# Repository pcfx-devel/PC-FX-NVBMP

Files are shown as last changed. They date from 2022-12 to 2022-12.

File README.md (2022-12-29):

# PC-FX-NVBMP

This is a design of a non-volatile backup memory board for the PC-FX. It's based on the
FX-BMP, but doesn't need batteries, and allows for several different sizes.

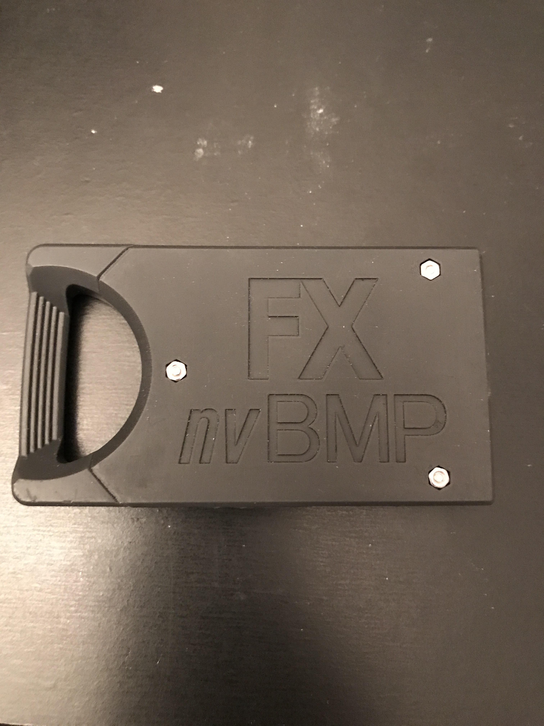
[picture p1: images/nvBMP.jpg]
FX-nvBMP cartridge


## Design

I designed the board using the free version of EAGLE, which is limited to 2 layers and
100mm x 100mm board size.  I have included the project files as well as the gerber outputs.

The board design is "Rev_B", as there was a minor fault in the REV_A design.

## Assembly

I have included gerber files, as well as BOM.csv and assembly.csv files, for use with
JLCPCB's SMD assembly service, if you are interested in taking advantage of that.

The second time I tried to order, the MRAM chip was no longer available, and I have noticed
in the past that the empty area would be filled with solder paste and would not be smooth
upon delivery, making it more difficult to solder my own parts on... so I made a special
"empty_MRAM_variant" set of gerbers/BOM.csv/assembly.csv files. The way I used these was to
order boards for assembly (including the level shift, OR gates, voltage regulator, and all the
passive components except the capactiors next to the MRAM chip; I sheared the stencil slightly
above the MRAM chip, and used the stencil to apply solder paste for just the MRAM chip and
2 capacitors, using a hotplate to heat the boards after mounting the missing parts.

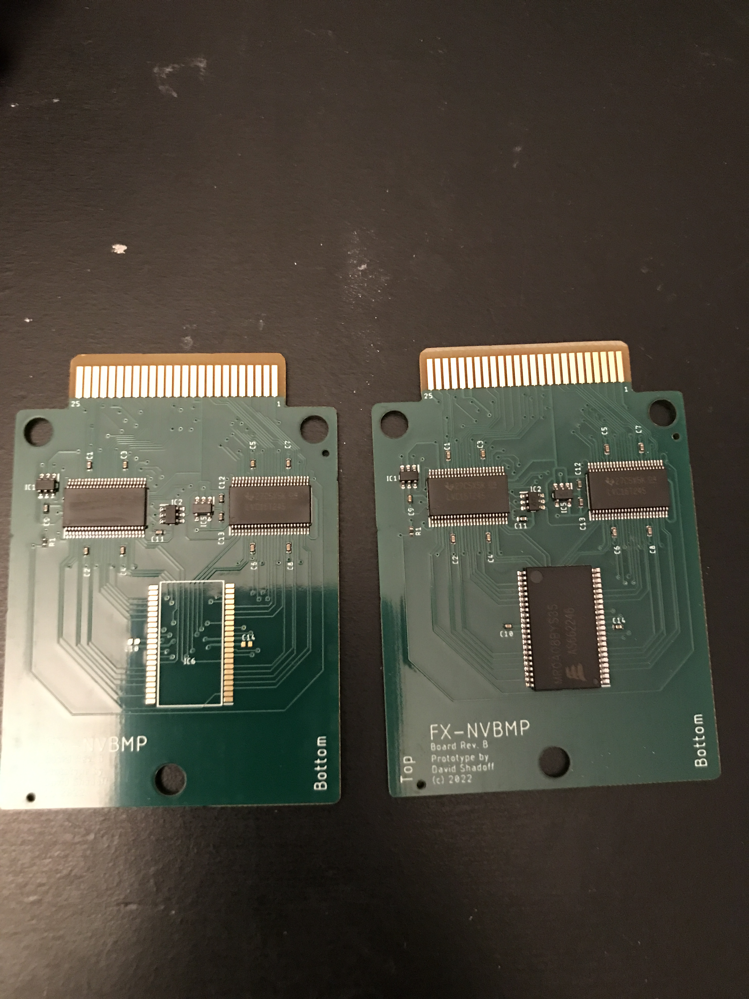
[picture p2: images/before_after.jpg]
empty_MRAM_variant


The MRAM part in use is MR0A08BCYS35 (TSOP2-44 package), but you could substitute any
other MR0A08... chip which uses the TSOP2-44 package (the 'Y' indicates this).
Additionally, MR2A08... (512KB) or MR4A08... (2MB) chips in the same line will also be
compatible as long as they also use the TSOP2-44 package.

## Case

You can also find the design for a case/enclosure, courtesy of Jeff Chen (Twitter: @jeffqchen).
This is suitable for any 3D printer; I particularly liked the resin prints I ordered online.
The case is designed to accept M2-12 socket-head screws and nuts.

## Circuit Design Concepts

I had originally considered using FRAM (Ferroelectric RAM) as the non-volatile memory type,
but when I went to search for parts, the 28V100 part was out of stock and had increased in
price significantly.  The next choice was MRAM (magnetoresistive RAM), which was available
(in very small quantities), slightly cheaper, and also had larger chips in the line which
shared the same footprint and pinout, so the board could be designed to accommodate the larger
chips without any changes (up to 2MB).

Also important, the pinout of the MRAM chip was very similar to the pinout of the FX-BMP
port, so a 2-layer board coul be made to accommodate it easier than FRAM.

As the PC-FX uses a 5V bus and these chips are based on 3V logic, level-shifters were required.

In order to drive the chip-select (low), a 3-input OR gate is used, requiring the following
lines to ALL be low in order to trigger the chip select:
 1. Cartridge select (keys in on range 0xE8000000 - 0xEFFFFFFF)
 2. A25 (narrows the range to 0xE8000000 - 0xEBFFFFFF)
 3. A24 (narrows the range to 0xE8000000 - 0xE9FFFFFF)

**NOTE:**\
The address lines are numbered according to the chip's address lines, which are not
necessarily the same as the CPU's address lines. The second byte on the memory chip is
actually memory address 0xE8000002, so the memory chip's A0 is effectively the CPU's A1).

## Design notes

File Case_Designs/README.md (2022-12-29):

# Case_Designs

These case deisgns were made Jeff Chen (Twitter: @jeffqchen), who has
graciously granted me permission to put them into the repository together
with the PC Board designs.

### Version 1:

This was a left/right half-case with similar dimensions to the original
PC-FX FX-BMP case.

It is designed to be held together by M2-12 screws (qty 3).

### Version 2:

This version made the sides slightly more asymmetric, with a carve-out on the
handle where the recess is on the PC-FX (to make it easier to remove).
Diagonals on the left side help guide the right side into place (although
there is a small amount of "rotation" possible).

There are also two different right-halves, one for the nvBMP, and one for the
Flash cartridge.

### Version 3:

This version has two principal changes from Version 2:

 1. There are "wells" on the left half to allow for the throuhg-hole pins of
the DIP version of the Flash board to be seated properly.
 2. In order to prevent the "rotation" when aligning the opposite sides, there
are interlocking notches on the diagonals. These can be a bit tight, but definitely
make a good mechinical alignment between sides for faster assembly with the screws.

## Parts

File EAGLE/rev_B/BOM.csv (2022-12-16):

Qty | Designator | Footprint | Comment | LCSC Part # (optional) | Description (optional)
12 | C1, C2, C3, C4, C5, C6, C7, C8, C9, C10, C11, C14 | C0402 | 100nF 16V | C1525 | Samsung CL05B104KO5NNNC 100nF 16V 0402
2 | C12, C13 | C0402 | 1uF 25V | C52923 | Samsung CL05A105KA5NQNC 1uF 25V 0402
1 | R1 | R0402 | 47K | C25741 | 62.5mW Thick Film Resistors 50V ±100ppm/_ ±1% -55_~+155_ 100k½ 0402 Chip Resistor - Surface Mount ROHS
2 | IC3, IC4 | TSSOP-48 | 74LVC16T245DGGR | C148170 | Texas Instruments 74LVC16T245DGGR, Dual, Bus Transceiver, 16-Bit Non-Inverting LVTTL, 1.65 5.5 V, 48-Pin TSSOP
2 | IC1, IC2 | SOT-23-6 | 74LVC1G332DBVR | C43368 | Texas Instruments 74LVC1G332DBVR, 3-Input OR Logic Gate, 1.65 5.5 V, 6-Pin SOT-23
1 | U$2 | Do Not Populate | Do Not Populate | Do Not Populate | Do Not Populate
1 | IC5 | SOT-23-5 | MIC5504-3.3YM5-TR | C88419 | 300mA 60dB@(1kHz) 380mV@(300mA) Fixed 3.3V~3.3V Positive 1 5.5V SOT-23-5 Linear Voltage Regulators (LDO) ROHS
1 | IC6 | TSOP2-44 | MR0A08BCYS35 | C246239 | Everspin MRAM 1Mb 3.3V 128Kx8 35ns Parallel MRAM

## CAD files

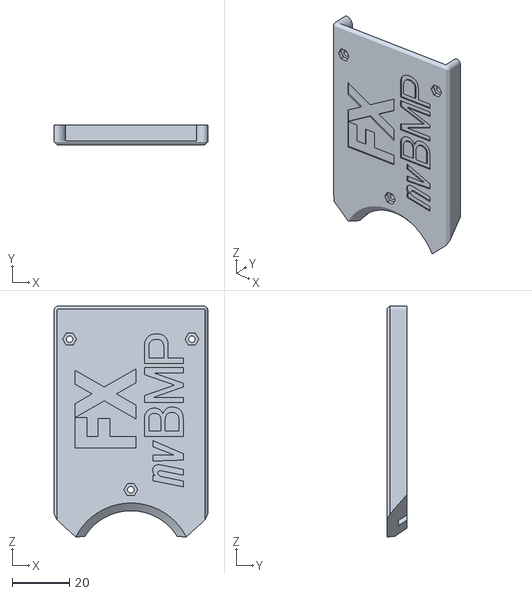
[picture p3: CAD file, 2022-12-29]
Case_Designs/Ver_3/Shell Right_mk3 - nvBMP.stl
53.8 x 7.03 x 80.8

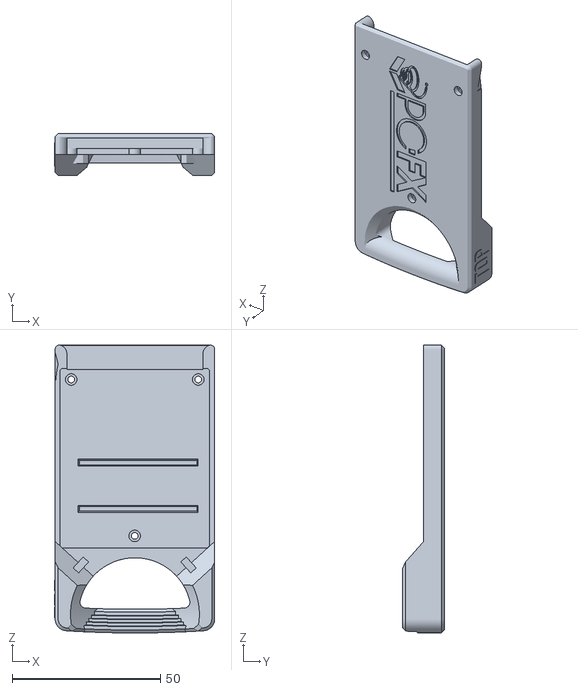
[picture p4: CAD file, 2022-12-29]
Case_Designs/Ver_3/Shell Left_mk3.stl
54.1 x 14.0 x 97.0

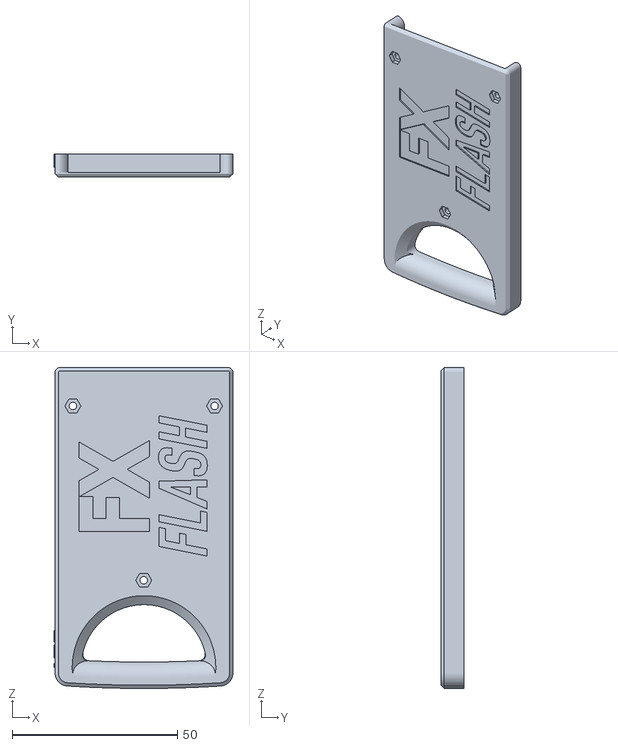
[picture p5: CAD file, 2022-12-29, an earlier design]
Case_Designs/Ver_1/Shell Right_orig.stl
54.1 x 7.03 x 97.0

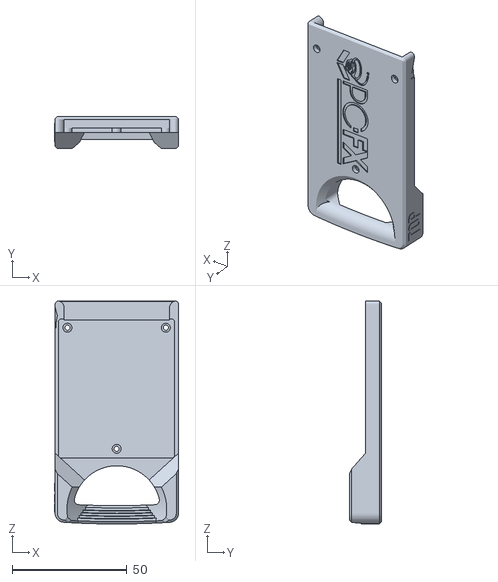
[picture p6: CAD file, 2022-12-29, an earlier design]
Case_Designs/Ver_2/Shell Left_mk2.stl
54.1 x 14.0 x 97.0

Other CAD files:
Case_Designs/Ver_3/Shell Right_mk3 - Flash.stl
Case_Designs/Ver_2/Shell Right_mk2 - nvBMP.stl
Case_Designs/Ver_1/Shell Left_orig.stl
Case_Designs/Ver_2/Shell Right_mk2 - Flash.stl

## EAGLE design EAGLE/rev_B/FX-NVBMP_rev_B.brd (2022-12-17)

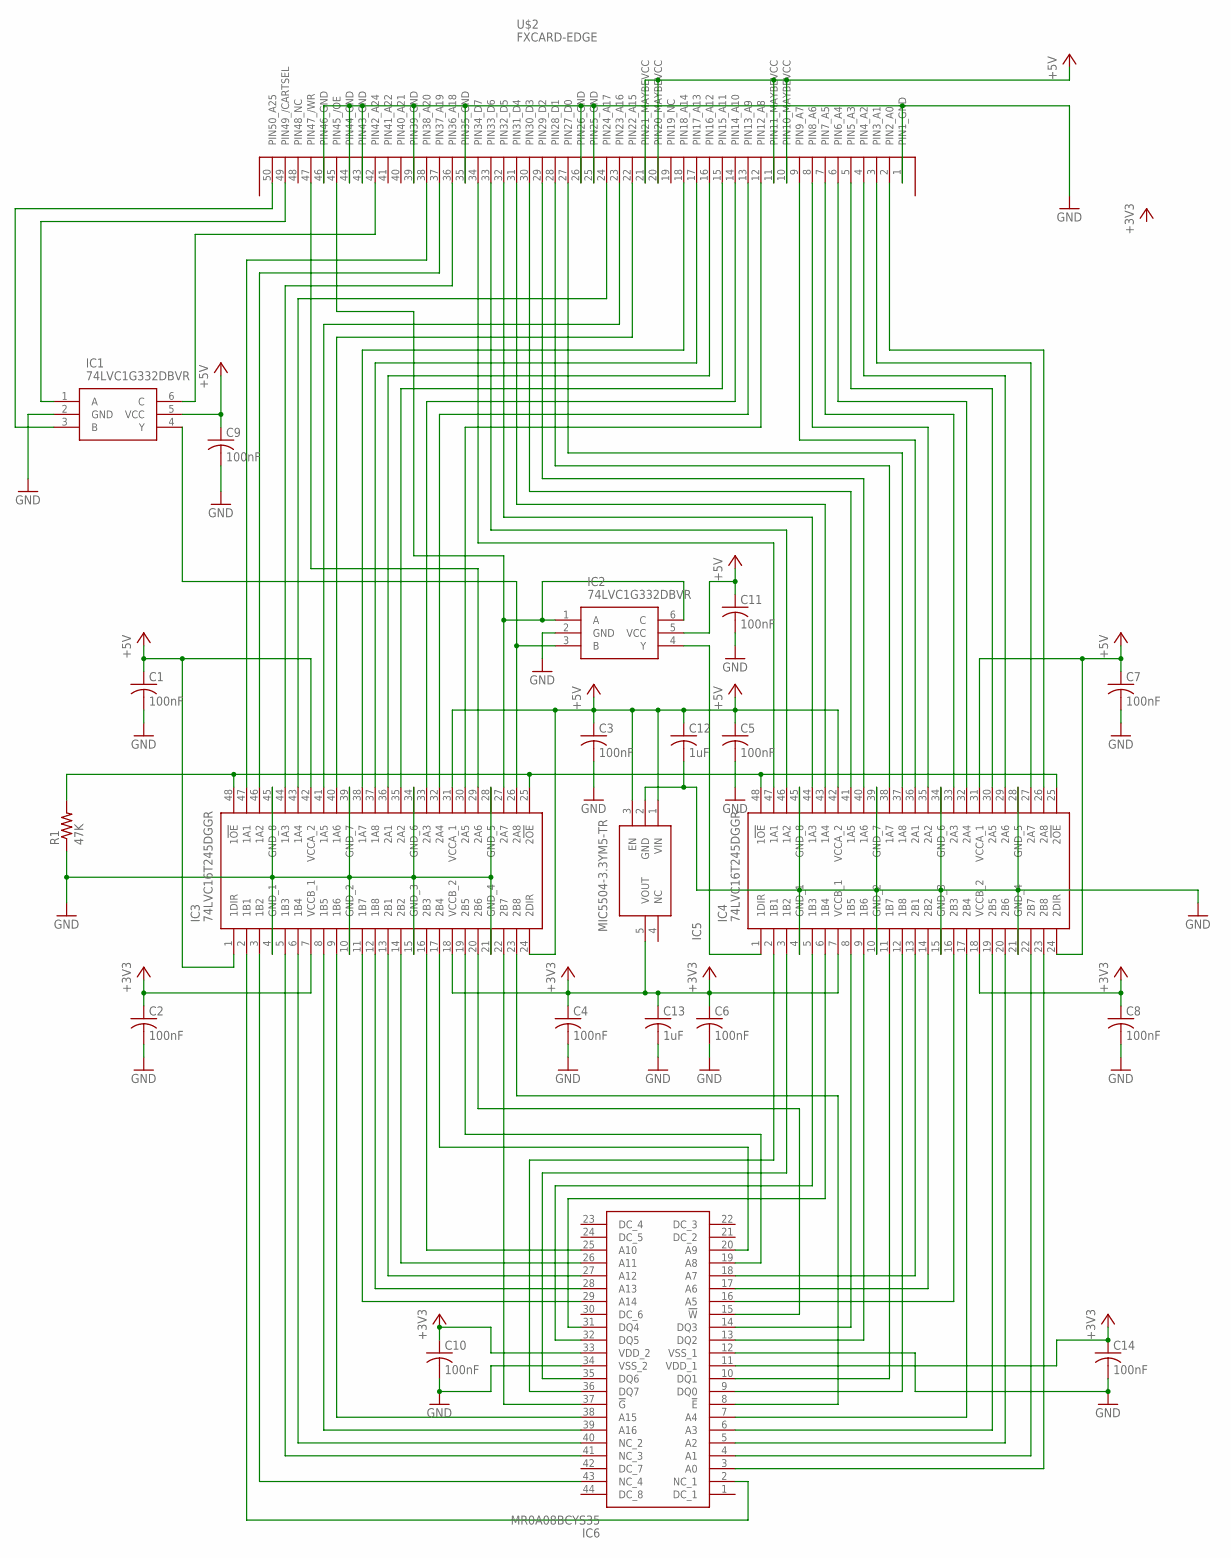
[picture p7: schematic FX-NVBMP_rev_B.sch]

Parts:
C1, C2, C3, C4, C5, C6, C7, C8, C9, C10, C11, C14: 100nF; C0402
C12, C13: 1uF; C0402
IC1, IC2: 74LVC1G332DBVR; SOT95P280X145-6N
IC3, IC4: 74LVC16T245DGGR; SOP50P810X120-48N
IC5: MIC5504-3.3YM5-TR; SOT95P280X145-5N
IC6: MR0A08BCYS35; SOP80P1176X120-44N
R1: 47K; R0402
U$2: FXCARD-EDGE

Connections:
+3V3: C2.1, C4.1, C6.1, C8.1, C10.1, C13.1, C14.1, IC3.7 (VCCB_1), IC3.18 (VCCB_2), IC4.7 (VCCB_1), IC4.18 (VCCB_2), IC5.5 (VOUT), IC6.11 (VDD_1), IC6.33 (VDD_2)
+5V: C1.1, C3.1, C5.1, C7.1, C9.1, C11.1, C12.1, IC1.5 (VCC), IC2.5 (VCC), IC3.1 (1DIR), IC3.24 (2DIR), IC3.31 (VCCA_1), IC3.42 (VCCA_2), IC4.24 (2DIR), IC4.31 (VCCA_1), IC4.42 (VCCA_2), IC5.1 (VIN), IC5.3 (EN), U$2.10 (PIN10_MAYBEVCC), U$2.11 (PIN11_MAYBEVCC), U$2.20 (PIN20_MAYBEVCC), U$2.21 (PIN21_MAYBEVCC)
GND: C1.2, C2.2, C3.2, C4.2, C5.2, C6.2, C7.2, C8.2, C9.2, C10.2, C11.2, C12.2, C13.2, C14.2, IC1.2 (GND), IC2.2 (GND), IC3.4 (GND_1), IC3.10 (GND_2), IC3.15 (GND_3), IC3.21 (GND_4), IC3.28 (GND_5), IC3.34 (GND_6), IC3.39 (GND_7), IC3.45 (GND_8), IC4.4 (GND_1), IC4.10 (GND_2), IC4.15 (GND_3), IC4.21 (GND_4), IC4.28 (GND_5), IC4.34 (GND_6), IC4.39 (GND_7), IC4.45 (GND_8), IC5.2 (GND), IC6.12 (VSS_1), IC6.34 (VSS_2), R1.1, U$2.1 (PIN1_GND), U$2.25 (PIN25_GND), U$2.26 (PIN26_GND), U$2.35 (PIN35_GND), U$2.39 (PIN39_GND), U$2.43 (PIN43_GND), U$2.44 (PIN44_GND), U$2.46 (PIN46_GND)
unnamed: IC4.37 (1A8), U$2.27 (PIN27_D0)
unnamed: IC4.38 (1A7), U$2.28 (PIN28_D1)
unnamed: IC4.40 (1A6), U$2.29 (PIN29_D2)
unnamed: IC4.41 (1A5), U$2.30 (PIN30_D3)
unnamed: IC4.43 (1A4), U$2.31 (PIN31_D4)
unnamed: IC4.44 (1A3), U$2.32 (PIN32_D5)
unnamed: IC4.46 (1A2), U$2.33 (PIN33_D6)
unnamed: IC4.47 (1A1), U$2.34 (PIN34_D7)
unnamed: IC4.26 (2A8), U$2.2 (PIN2_A0)
unnamed: IC4.27 (2A7), U$2.3 (PIN3_A1)
unnamed: IC4.29 (2A6), U$2.4 (PIN4_A2)
unnamed: IC4.30 (2A5), U$2.5 (PIN5_A3)
unnamed: IC4.33 (2A3), U$2.7 (PIN7_A5)
unnamed: IC3.43 (1A4), U$2.24 (PIN24_A17)
unnamed: IC4.35 (2A2), U$2.8 (PIN8_A6)
unnamed: IC4.36 (2A1), U$2.9 (PIN9_A7)
unnamed: IC4.32 (2A4), U$2.6 (PIN6_A4)
unnamed: IC3.44 (1A3), U$2.36 (PIN36_A18)
unnamed: IC3.46 (1A2), U$2.37 (PIN37_A19)
unnamed: IC3.47 (1A1), U$2.38 (PIN38_A20)
unnamed: IC1.4 (Y), IC2.3 (B), IC3.26 (2A8)
unnamed: IC3.25 (2!OE), IC3.48 (1!OE), IC4.25 (2!OE), IC4.48 (1!OE), R1.2
unnamed: IC4.23 (2B8), IC6.3 (A0)
unnamed: IC4.22 (2B7), IC6.4 (A1)
unnamed: IC4.20 (2B6), IC6.5 (A2)
unnamed: IC2.4 (Y), IC4.1 (1DIR)
unnamed: IC4.19 (2B5), IC6.6 (A3)
unnamed: IC4.17 (2B4), IC6.7 (A4)
unnamed: IC4.16 (2B3), IC6.16 (A5)
unnamed: IC4.14 (2B2), IC6.17 (A6)
unnamed: IC4.13 (2B1), IC6.18 (A7)
unnamed: IC4.12 (1B8), IC6.9 (DQ0)
unnamed: IC3.30 (2A5), U$2.12 (PIN12_A8)
unnamed: IC3.32 (2A4), U$2.13 (PIN13_A9)
unnamed: IC3.33 (2A3), U$2.14 (PIN14_A10)
unnamed: IC3.35 (2A2), U$2.15 (PIN15_A11)
unnamed: IC3.36 (2A1), U$2.16 (PIN16_A12)
unnamed: IC3.37 (1A8), U$2.17 (PIN17_A13)
unnamed: IC3.38 (1A7), U$2.18 (PIN18_A14)
unnamed: IC3.40 (1A6), U$2.22 (PIN22_A15)
unnamed: IC3.41 (1A5), U$2.23 (PIN23_A16)
unnamed: IC3.29 (2A6), U$2.47 (PIN47_/WR)
unnamed: IC2.1 (A), IC2.6 (C), IC3.27 (2A7), U$2.45 (PIN45_/OE)
unnamed: IC1.3 (B), U$2.50 (PIN50_A25)
unnamed: IC1.1 (A), U$2.49 (PIN49_/CARTSEL)
unnamed: IC1.6 (C), U$2.42 (PIN42_A24)
unnamed: IC4.11 (1B7), IC6.10 (DQ1)
unnamed: IC4.9 (1B6), IC6.13 (DQ2)
unnamed: IC4.8 (1B5), IC6.14 (DQ3)
unnamed: IC4.6 (1B4), IC6.31 (DQ4)
unnamed: IC4.5 (1B3), IC6.32 (DQ5)
unnamed: IC4.3 (1B2), IC6.35 (DQ6)
unnamed: IC4.2 (1B1), IC6.36 (DQ7)
unnamed: IC3.19 (2B5), IC6.19 (A8)
unnamed: IC3.17 (2B4), IC6.20 (A9)
unnamed: IC3.16 (2B3), IC6.25 (A10)
unnamed: IC3.14 (2B2), IC6.26 (A11)
unnamed: IC3.13 (2B1), IC6.27 (A12)
unnamed: IC3.12 (1B8), IC6.28 (A13)
unnamed: IC3.11 (1B7), IC6.29 (A14)
unnamed: IC3.9 (1B6), IC6.38 (A15)
unnamed: IC3.8 (1B5), IC6.39 (A16)
unnamed: IC3.6 (1B4), IC6.40 (NC_2)
unnamed: IC3.5 (1B3), IC6.41 (NC_3)
unnamed: IC3.3 (1B2), IC6.43 (NC_4)
unnamed: IC3.2 (1B1), IC6.2 (NC_1)
unnamed: IC3.20 (2B6), IC6.15 (!W)
unnamed: IC3.23 (2B8), IC6.8 (!E)
unnamed: IC3.22 (2B7), IC6.37 (!G)

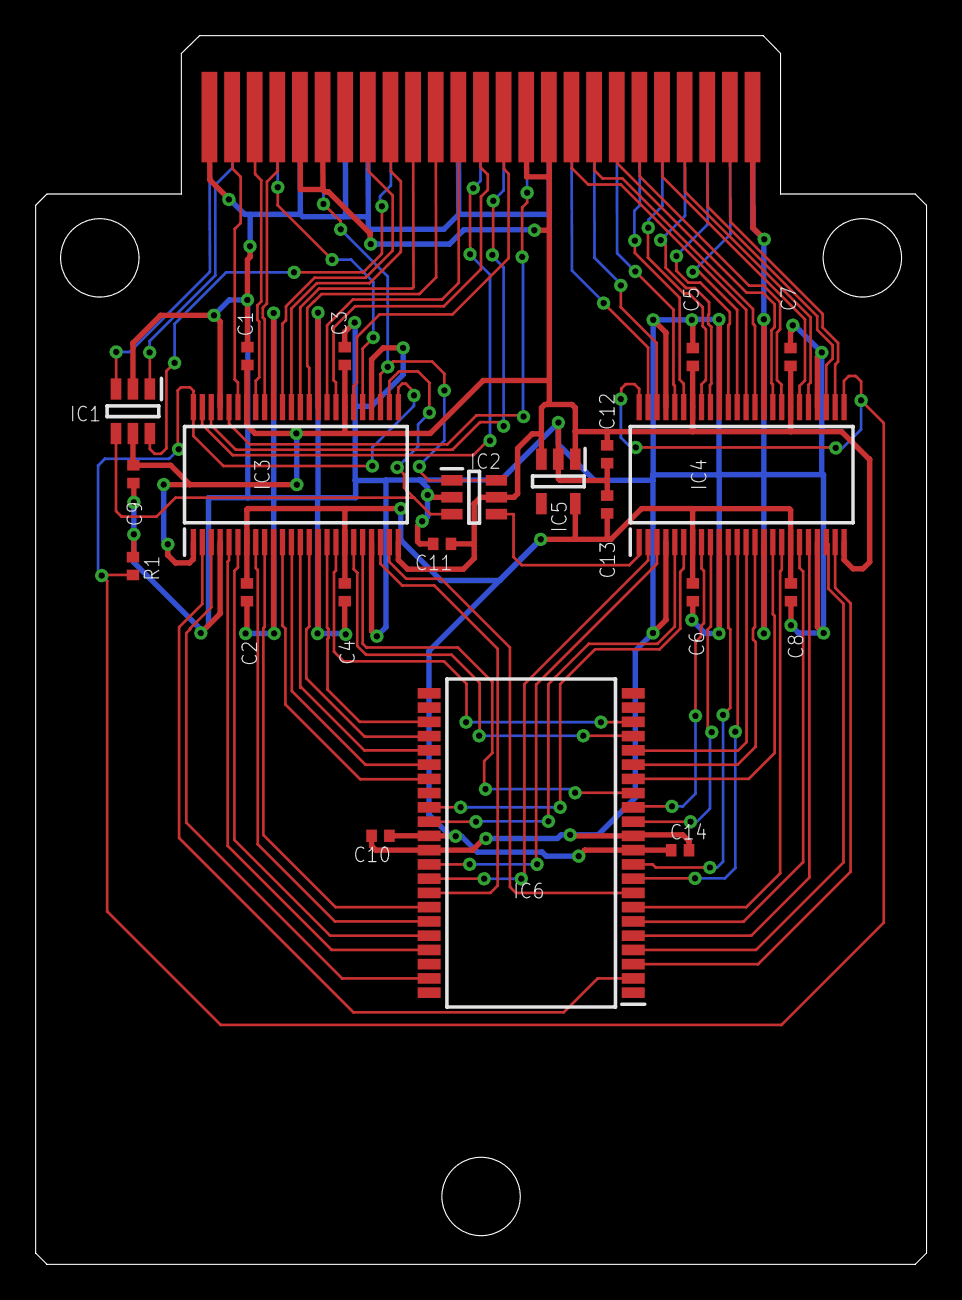
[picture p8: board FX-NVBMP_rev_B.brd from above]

Board: 2 copper layers, 50.0 x 69.0 mm, 22 parts (0 on the bottom side), 72 nets.

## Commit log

2022-12-17 Fix silkscreen on Rev. B
    [FX-NVBMP_rev_B.brd]
2022-12-29 Initial release
    [BOM_noram.csv, FX-NVBMP_rev_A.brd, FX-NVBMP_rev_A.sch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]

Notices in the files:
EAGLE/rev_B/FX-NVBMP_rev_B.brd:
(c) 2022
